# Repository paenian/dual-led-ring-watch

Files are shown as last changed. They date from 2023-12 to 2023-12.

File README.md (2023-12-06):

# dual-led-ring-watch
3D Printed Wall-Mounted NeoPixel LED Clock with NTP Synchronization

This was originally developed by [Bastel Garage](https://github.com/bastelgarage) and is being modified by Paul Chase.

Particularly, I've added a second hand to the clock, and will also be uploading STLs for a larger version based on neopixel strips.
The larger version will use identical code, just greater spacing on the LEDs.
My goal is to display the clock in a makerspace - so I'll also be adding numbers to the dial, so hopefully folks can read it even if
they are unfamiliar with analog clocks.

## Description
This project is a creative take on a digital clock, utilizing a circular arrangement of NeoPixel LEDs that face towards the wall, casting an ambient glow that visually represents the time. It is designed to be wall-mounted with the LED ring's connection point situated at the bottom for a cleaner appearance. The clock synchronizes with NTP servers for precise timekeeping and automatically adjusts for daylight saving time in the Central European Timezone (CET/CEST).

NeoPixel LED Clock

## Features
- **Ambient Wall Display**: The LED ring projects light onto the wall, creating a halo effect that is both functional and decorative.
- **NTP Time Synchronization**: Ensures the time displayed is always accurate by syncing with network time protocol servers.
- **Daylight Saving Time Ready**: With the Timezone library, it transitions smoothly for daylight saving time changes in CET/CEST zones.
- **Configurable LED Ring**: A strip of 2x 60 NeoPixel LEDs is arranged in a ring, with the ability to change colors to indicate hours and minutes.
- **Discreet Bottom Connection**: The power and data connections for the LED ring are located at the bottom, minimizing visibility and maintaining the clock's aesthetic.

## Hardware Components
- ESP8266 WiFi Microcontroller [WeMos D1 mini ESP8266](https://www.bastelgarage.ch/wemos-d1-mini-esp8266-nodemcu-lua-board)
- 2x 60 LED NeoPixel Ring (172mm) [60 LED 172mm Ring](https://www.ebay.co.uk/itm/132996155861)
- 5V Power Supply (adequate for powering the LED ring) [5V 2000mA USB](https://www.bastelgarage.ch/5v-2000ma-usb-netzteil-ac-dc-adapter-weiss)
- Logic Level Shifter (if needed by the ESP8266) [Logic Level Converter 2-Kanal 5V / 3.3V](https://www.bastelgarage.ch/logic-level-converter-2-kanal-5v-3-3v)

## US-based Hardware

## Software Libraries
- `ESP8266WiFi` for WiFi functionality.
- `WiFiManager` for easy WiFi setup without hardcoding credentials.
- `Timezone` for handling local time and daylight saving adjustments.
- `TimeLib` for time-related functions.
- `NTPClient` for retrieving accurate time from internet servers.
- `Adafruit_NeoPixel` for controlling the NeoPixel LEDs.

## Setup Instructions
1. Secure the NeoPixel LED ring to the desired wall location, ensuring the connection point is oriented at the bottom.
2. Wire the LED ring to the ESP8266, taking care to connect to the correct data input and provide sufficient power.
3. Upload the provided sketch to the ESP8266 using an IDE like Arduino IDE.
4. At first startup, the device will create a WiFi access point named "NeoPixelClock" for configuration.
5. Connect to this access point with a smartphone or computer to input your WiFi network details.
6. The clock will then connect to your network and begin displaying the time, casting a beautiful ambient light onto the wall.

## Customization
Modify the `setTimeOnLEDs` function in the code to personalize the LED colors for hours and minutes to your taste or match your interior design.

Layers

## Tags

- `NeoPixel`
- `LED-Clock`
- `NTP-Synchronization`
- `ESP8266`
- `WiFi`
- `IoT`
- `Home-Automation`
- `DIY`
- `Arduino`
- `Timekeeping`
- `Wall-Clock`
- `Daylight-Saving`
- `CET`
- `CEST`
- `Ambient-Lighting`
- `bastelgarage`

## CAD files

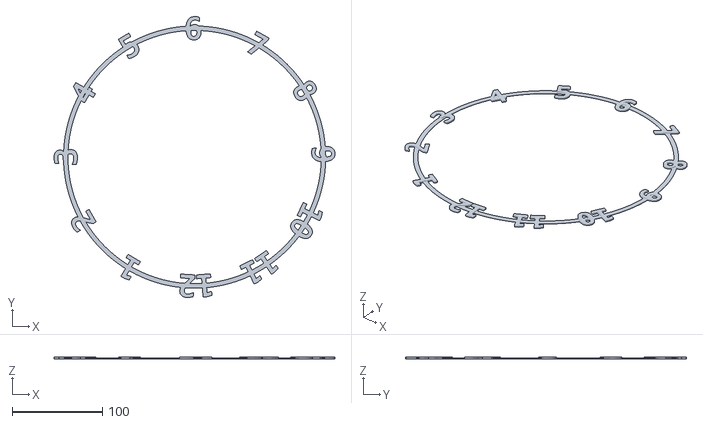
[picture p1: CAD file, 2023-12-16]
new_stl/large_clock/large numbers.stl
310.6 x 310.7 x 2.00

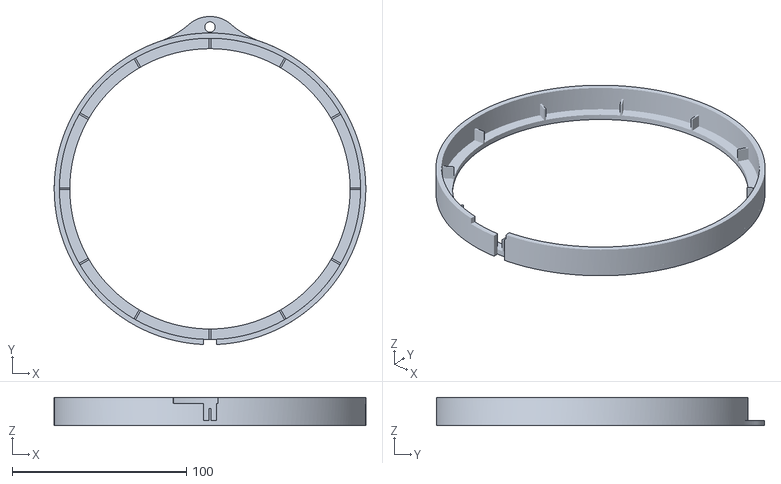
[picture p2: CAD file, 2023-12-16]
new_stl/small_clock/base - wall mount.stl
179.0 x 188.4 x 16.3

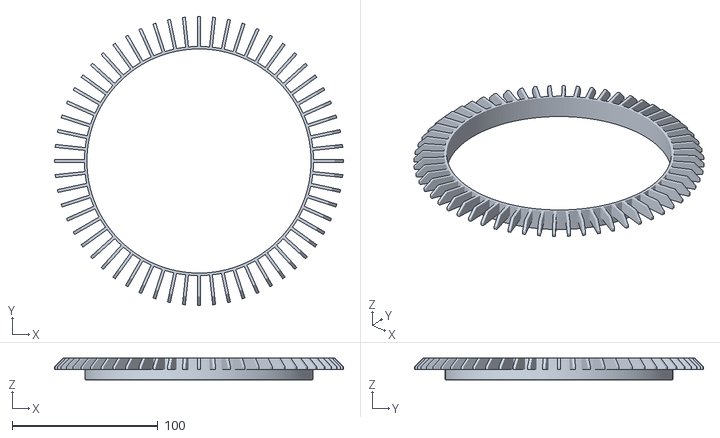
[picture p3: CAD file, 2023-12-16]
new_stl/small_clock/small light minute.stl
198.0 x 198.0 x 15.0

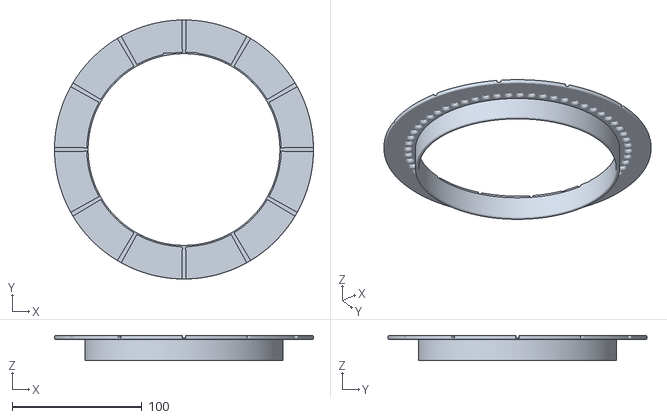
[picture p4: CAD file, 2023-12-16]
new_stl/small_clock/small clock face.stl
200.0 x 200.0 x 19.5

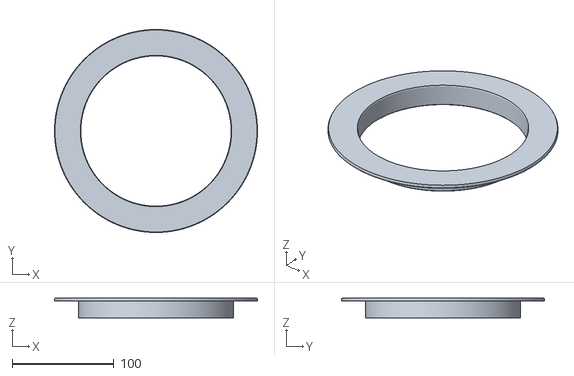
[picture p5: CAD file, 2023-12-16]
new_stl/small_clock/blank clock face.stl
200.0 x 200.0 x 19.5

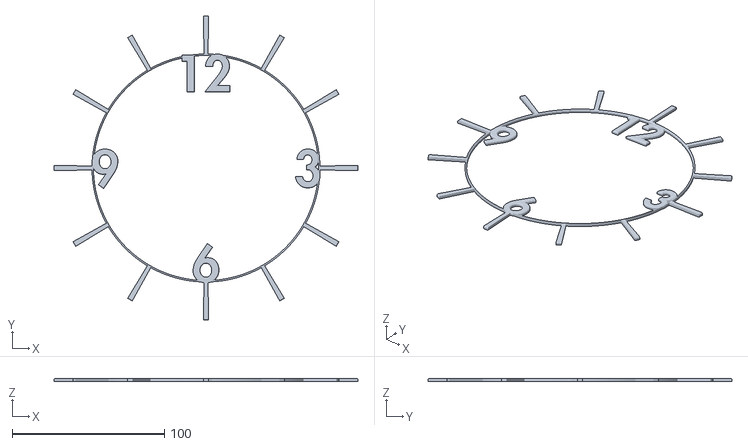
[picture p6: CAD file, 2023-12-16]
new_stl/small_clock/small numbers.stl
200.0 x 200.0 x 2.00

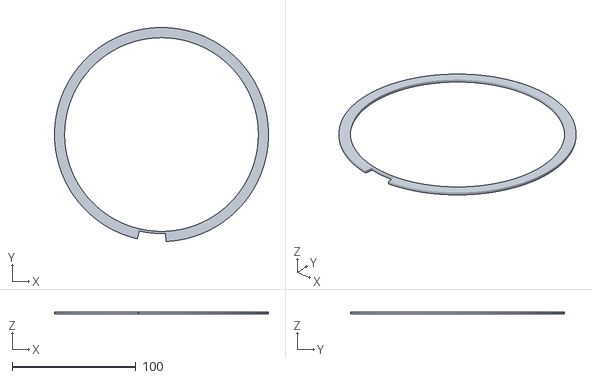
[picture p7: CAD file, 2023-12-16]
new_stl/small_clock/WS2812 spacer.stl
173.0 x 172.9 x 2.00

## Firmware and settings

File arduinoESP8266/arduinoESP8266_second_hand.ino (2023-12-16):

/**
 * NeoPixel Uhr mit NTP-Synchronisierung
 * Dieses Skript steuert einen NeoPixel LED-Ring, um die aktuelle Zeit anzuzeigen,
 * synchronisiert über NTP (Network Time Protocol).
 *
 * Erstellt am: 04.11.2023
 * Letzte Aktualisierung: 04.11.2023 V1.0
 *
 * Autor: Alf Müller / purecrea gmbh Schweiz / www.bastelgarage.ch
 * Updated by Paul J Chase
 *
 *
 * I've added English comments where I thought necessary - most of the setup is the same
 * I modified the main loop to update every LED every time - I prefer constant-time loops
 * on micros - but for the most part the logic is Alf's.
 *
 *
 * Copyright (c) 2023 Alf Müller. Alle Rechte vorbehalten.
 * Veröffentlichung, Verbreitung und Modifikation dieses Skripts sind unter der
 * Bedingung der Namensnennung erlaubt und lizenzfrei.
 *
 * Modifications Copyright (c) 2023 Paul Chase. All rights reserved.
 * Publication, distribution and modification of this script are under the
 * Condition of attribution permitted and royalty-free.
 */
#include <ESP8266WiFi.h>
#include "WiFiManager.h"                    //https://github.com/tzapu/WiFiManager
#include <Timezone.h>                       //https://github.com/JChristensen/Timezone
#include <TimeLib.h>                        //https://github.com/PaulStoffregen/Time
#include <NTPClient.h>
#include <WiFiUdp.h>
#include <Adafruit_NeoPixel.h>
#define PIN D6
#define NUMPIXELS 120


#define DEBUG 1    //comment this out to remove serial port chatter

// Initialisierung der NeoPixel-Bibliothek
Adafruit_NeoPixel pixels(NUMPIXELS, PIN, NEO_GRB + NEO_KHZ800);

// Initialisierung des NTP-Clients
WiFiUDP ntpUDP;
NTPClient timeClient(ntpUDP, "pool.ntp.org", 3600, 60000);

// Zeitzone für Zentraleuropa definieren
//TimeChangeRule CEST = {"CEST", Last, Sun, Mar, 2, 120};   // Sommerzeit: Letzter Sonntag im März um 2 Uhr morgens +2 Stunden
//TimeChangeRule CET = {"CET", Last, Sun, Oct, 3, 60};      // Standardzeit: Letzter Sonntag im Oktober um 3 Uhr morgens +1 Stunde
//Timezone CE(CEST, CET);
TimeChangeRule usEDT = {"EDT", Second, Sun, Mar, 2, -240};    // eastern daylight savings time: -240 minutes or -4 hours
TimeChangeRule usEST = {"EST", First, Sun, Nov, 2, -300};     // eastern standard time : -300 minutes or -5 hours
Timezone usEastern(usEDT, usEST);

void setup() {
  #ifdef DEBUG
    Serial.begin(500000);  // be sure to set your serial monitor to 500000!
    Serial.println("Serial is working");
  #endif
  
  pixels.begin();
  WiFiManager wifiManager;
  wifiManager.autoConnect("NeoPixelClock");
  timeClient.begin();
}

void loop() {
  // Aktualisiere die NTP-Zeit  // Update NTP time
  timeClient.update();

    // Hole die aktuelle Zeit in UTC  // get the time in UTC
  time_t utc = timeClient.getEpochTime();

  // Wandele die UTC-Zeit in lokale Zeit um  // convert UTC to local time
  time_t local = usEastern.toLocal(utc);

  // Hole die aktuelle Stunde, Minute und Sekunde von der NTP-Zeit  // get the hour, minute and seconds
  int stunden = hour(local);
  int minuten = minute(local);
  int sekunde = second(local);  // Translated into German to keep the code feeling right


  // Setze die LEDs basierend auf der aktuellen Zeit  // this function displays the time
  setTimeOnLEDs(stunden, minuten, sekunde, 0, 0, 255, 0, 127, 0, 255, 0, 0);  // Blau für Minuten, Grün für Stunden, red for seconds
  delay(100);  // Warte eine Sekunde bevor der nächste Durchlauf beginnt  // waiting 1/10 second so we can do seconds
}

/* int clamp(int num)
 *
 * simple function added to ensure we never ask for brightness that's too bright
 * also a good reason to use ints and not bytes everywhere, so overflow can be handled easily
*/
int clamp(int num) {
  return (num>255) ? 255 : num;
}

/* void setTimeOnLEDs(int stunden, int minuten, int sekunde, byte rMinuten, byte gMinuten, byte bMinuten, byte rStunden, byte gStunden, byte bStunden, byte rSekunde, byte gSekunde, byte bSekunde )
 *
 * this sets every LED to the current time.
 */
void setTimeOnLEDs(int stunden, int minuten, int sekunde, byte rMinuten, byte gMinuten, byte bMinuten, byte rStunden, byte gStunden, byte bStunden, byte rSekunde, byte gSekunde, byte bSekunde ) {
  //pixels.clear();  // Schalte alle LEDs aus  //we'll set every LED manually, thankyouverymuch.

  #ifdef DEBUG
    Serial.print("Displaying Time: ");
    Serial.print(stunden);
    Serial.print(":");
    Serial.print(minuten);
    Serial.print(":");
    Serial.println(sekunde);
  #endif
 
  //calculate the number of LEDs to light for the hours
  stunden = stunden % 12;  // Using a 12 hour clock
  int stundenAnzahl = stunden * 5 + minuten / 12;  // Jede Stunde hat 5 LEDs, jede Minute fügt 1/12 einer Stunde hinzu //Each hour has 5 LEDs, each minute adds 1/12 of an hour
  
  #ifdef DEBUG
    Serial.println("Light up hour LEDs 1->" + stundenAnzahl);
  #endif

   // This goes around the minute and hour rings at the same time
  for (int i = 0; i < 60; i++) {
    // i = minutes - and also there are 60 LEDs... so that's confusing.  but for this loop: i = minutes = stundenAnzahl positions
    // We'll calculate the LED indices later.
    #ifdef DEBUG
      Serial.print("LED ");
      Serial.print(i);
      Serial.print(": ");
    #endif

    //for each pixel - should it turn on?
    byte rm = 0; byte gm = 0; byte bm = 0;  // minute colors
    byte rh = 0; byte gh = 0; byte bh = 0;  // hour colors

    //this sets the second LED's color.  It mixes the second color with the hour/minute color later.  Note the second lights on both rings.
    if(i == sekunde){
        rm += rSekunde; gm += gSekunde; bm += bSekunde;  // minute colors
        rh += rSekunde; gh += gSekunde; bh += bSekunde;  // hour colors
    }

    //figure out if this LED should be lit as one of the minutes
    if(i < minuten){
        rm += rMinuten; gm += gMinuten; bm += bMinuten;  // minute colors
    }

    //figure out if this LED should be lit as one of the hours
    if(i < stundenAnzahl){
        rh += rStunden; gh += gStunden; bh += bStunden;  // hour colors
    }
   
    // the LED ring starts at the bottom, and the hours go counterclockwise... cuz the ring faces the wrong way.
    // so Minute 0 lights up LED 29 - do that calculation at the lighting
    // all minutes from 0->cur minute light as well.
    // For hours, they start at 90-i and count down to 60 before popping over to 119
   
    // set the color on the minute ring
    #ifdef DEBUG
      Serial.print("Pixel Translation - M: ");
      Serial.print(((i+29) % 60));
    #endif
    pixels.setPixelColor((i+29) % 60, pixels.Color(clamp(rm), clamp(gm), clamp(bm)));

    //set the color on the hour ring
    #ifdef DEBUG
      Serial.print(" Pixel Translation - H: ");
      Serial.println(((90-i) % 60) + 60);
    #endif
    pixels.setPixelColor(((90-i) % 60) + 60, pixels.Color(clamp(rh), clamp(gh), clamp(bh)));
  }

  pixels.show();  // Aktualisiere den Strip, um die Änderungen anzuzeigen  // yeah let's turn it on :-)
}

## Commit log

2023-12-06 Create arduinoESP8266_second_hand.ino
    Updated and cleaned the code for upload... so I'll have to verify correctness and compiling later, but it should be close.
    [arduinoESP8266_second_hand.ino]
2023-12-07 Update arduinoESP8266_second_hand.ino
    Had to break out the debug serial prints - also adjusted the color values, the green is much brighter than the other two, so it got dimmed.
2023-12-15 Adding all the STLs from my builds
    I re-did a lot of the originals in new_stl/small_clock, and my big guys are
    in large_clock
    [base - wall mount.stl, blank clock face.stl, light minute.stl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]
2023-12-16 Cleaning up the STLs - and adding a mounting hole
    [WS2812 spacer.stl, base - wall mount.stl, blank clock face.stl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]
